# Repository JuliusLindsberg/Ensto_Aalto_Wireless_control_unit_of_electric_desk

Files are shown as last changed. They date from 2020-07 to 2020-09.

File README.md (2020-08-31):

# Wireless contol unit of electric desk
This is an Aalto University student project which aims to produce a functional prototype for a wireless controller of an electric desk. It is being developed
in collaboration with Ensto. Software will be published under a very permissive MIT license. See the licence file disclosed in this repository for details.
## Hardware
Our aim currently is to provide a working solution for only specific hardware. In our code there may or may not be useful generalizations for other types of
hardware choices too but quite certainly our solution is not going to work right out the box.
### Microcontroller: NRF52840
NRF52840 provides adequate support for bluetooth low energy and potential for control via NFC tags.
### Desk interface module
Module for interfacing between nrf52840 Dev Kit and Martela electric desk. Not necessarily compatible with other manufacturers. KiCad files included.
## Software

### Zephyr RTOS
Zephyr RTOS is an open source real time operating system which we use in this project. It provides some device bindings for the NRF52840.
There is also a fork of Zephyr maintained by Nordic Semiconductors which may have helpful examples. However, it unfortunately doesn't directly support NFR52840. 
https://github.com/nrfconnect/sdk-nrf
### C++
Programming language used is C++ or plain C. Not at all every feature of C++ is applicable due to constraints imposed by Zephyr OS.
See: https://docs.zephyrproject.org/1.9.0/kernel/other/cxx_support.html
### Our code
See doc/API.md for our API reference.
### Arduino table control folder
Contents of said folder don't have an active role in the project and are there just for storage purposes only. They were used to try out some concepts and
electrical circuits with a seperate arduino board simultaneously.
## Getting started
Developing and building our project should be not very different from building any other zephyr project. As a bit of a warning Zephyr's work enviroment
takes a lot of space (several gigabytes) from your hard drive.
Developing Zephyr programs should be possible with any major operating system but so far we have used only Linux so other enviroments are a case of untested waters.
### Setting up the work enviroment
In order to build our code follow these instructions:
https://docs.zephyrproject.org/latest/getting_started/index.html
Then clone this git repository inside the zephyrproject/zephyr folder. With a little tweaking it probably is possible to build the project ouside zephyr folder
too but just cloning this repository inside it seems to be the most convenient way available.
### Building our project
We use Zephyr's west tool to build our project in a similiar fashion as the tutorial above does. In order to build this project navigate to this
git repository in your shell and then execute:
```
west build -p auto -b nrf52840dk_nrf52840 ./
```

If your microcontroller is not NRF52840, then -b option should naturally be something else.
### Flashing into the microcontroller
```
west flash
```
should work just fine as with any other Zephyr project. flash command also tries to build the project if it isn't up to date. So the build command might be redundant for your workflow.

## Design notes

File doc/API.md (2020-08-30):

# Introduction

Software implementation of our project has been divided into c++ classes with the aim of encapsulating different functionalities in a logical way
and making everything more modular. API documentation will reflect this and therefore consist mostly of class descriptions.
Further explanations into the Zephyr's API reference can be found from: https://docs.zephyrproject.org/latest/boards/arm/nrf52840dk_nrf52840/doc/index.html
Despite it's name this document does not attempt to be a sterile API reference nor is it written by an expert on the topic. Instead, it is designed to explain
itself as well as possible from a subjective point of view in an attempt to help beginners to Zephyr avoid potential pitfalls.

Also it is imperative that a developer learns about Zephyr's inner workings from Zephyr's own tutorials. For example:
https://docs.zephyrproject.org/latest/guides/dts/intro.html#devicetree-intro <- which is a link to Zephyr project's device tree introduction in case the link dies.
Coming from personal experience, relying too heavily in deducting Zephyr's functionality from it's own code samples is not the most efficient method of
understanding it.

## DebugBlinker
DebugBlinker is a lightweight class that other classes can use for debugging. The final prototype will most likely have no use for LEDs as they will not be visible to
the end user. User of this class can create as many DebugBlinker objects as they want: they do not imply any sort of exclusive ownership of a led. However,
DebugBlinker's functionality currently is not thread-safe. LED4 is reserved for declaring an exeption: If LED4 is lit then some part of the program has called
declareException() function.

Non-Member functions:

### void declareException()

Lights up LED4 as a signal of exceptional circumstances faced somewhere during the execution of the program. It is supposed to replace a hole left by c++ standard library's exception handling as unfortunately Zephyr currently does not support it.

Member functions:

### DebugBlinker(int led_)

constructor for the DebugBlinker object. Supports leds 1, 2 and 3.
This is the only way to create an object of this class currently that is supported by the API.

### void ledOn()

Will light up a led. Supports leds 1, 2 and 3.

### void ledOff(int led)

Will power off a led. Supports leds 1, 2 and 3.

## DebugPrinter

DebugPrinter is another lightweight class that can be used for debugging. It was used in conjunction with Segger's J-Link SWOWiever tool for debug output.
Zephyr does also provide a function called printk for serial output but as it didn't work immediately for unknown reasons and although SWOViewer was a clumsy-ish
compromise it did eventually satisfy all of the group's needs for debugging and as such not much research was put into the problem which probably
would have been proven out to be very solvable. For further development using printk is still most likely a more preferable solution as it is being used in examples.

DebugPrinter has << operator overloading and it can be used as if it were std::cout with the exception that it is not a static class and should be instead
interacted through DebugPrinter objects. The first instance of DebugPrinter initializes SWO and SWOViewer and can be configured to work only after that.
Therefore it is recommended to create one DeubgPrinter Object right in the beginning of main(): another example of why printk would have indeed been more preferable.

Member functions:

### PrintString(char* string)
Prints a null-terminated-string to the SWO terminal. Can also be used with << operator
### PrintChar(char c)
Prints a single char to the SWO terminal. Can also be used with << operator
### PrintInt(int number)
Prints a number to the SWO terminal. Can also be used with << operator

## MotorController

This class is responsible for emulating the control signal of the desk's physical button presses. It determines which control signals should be listened to at what
times as a finite state machine. Currently it has two states: BUTTON and BLUETOOTH. However, additional states could be defined for additional states. BLUETOOTH state
might actually be a bit misrepresenting as it isn't actually directly responsible for listening to bluetooth signals. It just steers the table towards a target height
automatically based on steerRequest() function calls.

Currently, unfortunately, creating multiple objects of this class causes undefined behaviour!

### enum ButtonState
The electric desk's control button has four logical states it can be in. Our microcontroller tries to emulate them so that when a user presses the button
our controller functions as if it wouldn't be there at all catching the signal.

### enum ControlState
The MotorController internally functions as a finite state machine. Currently it has two states: BLUETOOTH and BUTTON. Every state has it's respective member
function responsible for sending the appropriate control signals to the motor and transitioning between states.

Member functions:

### void steerRequest(int newTargetHeight)

Tells MotorController to steer itself autonomously to a set target height. newTargetHeight represents reverse-engineered encoder steps which we spy and as such 
the distance traversed isn't strictly bound to any physical unit of height. Theoretically one encoder step does represent a certain constant distance but where
the table actually sets in within these boundaries could vary. The resolution of the table's encoder steps between the most upwards position and down position
is between 0 and somewhere around 400. Requests that differ from this range are currently not being ignored or cropped to physical limits by the function.

### ControlState getState()

Returns in which control state MotorController is in right now.

### void run()

a forever blocking function which keeps running the internal state machine logic to steer the table according to their respective user inputs.

### EncoderAnalyzer

This class analyzes the data which the desk's encoder provides with the help of an ADC pin. It is used by MotorController class internally and provides no useful
functionality outside of that.

## BluetoothModule.hpp

This is a more of a c-style interface responsible for implementing bluetooth functionality. It mostly has asynchronous functions and callback functions that describe
what is supposed to happen after event x happening. The c-style approach is because from our experience asynchronous functions combined with c++-style objects
do not really fit together well. It defines a custom bluetooth GATT service that has a 128-bit UUID of 6495c7ad-e0cc-4c2c-87c8-e8ad2f964b03 and advertises said service this UUID should be able to be changed with just one line of code. Naturally though the code of your BLE clients should be updated as well.

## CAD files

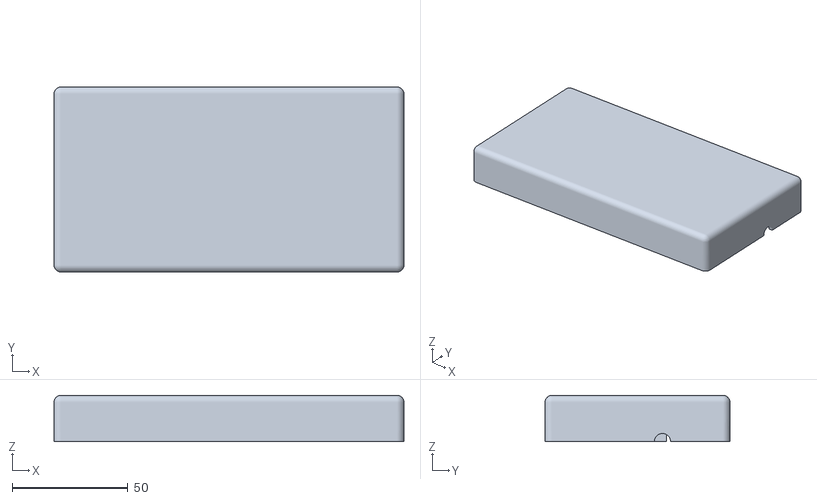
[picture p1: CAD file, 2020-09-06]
control_box_upper.stl
151.4 x 80.0 x 20.0

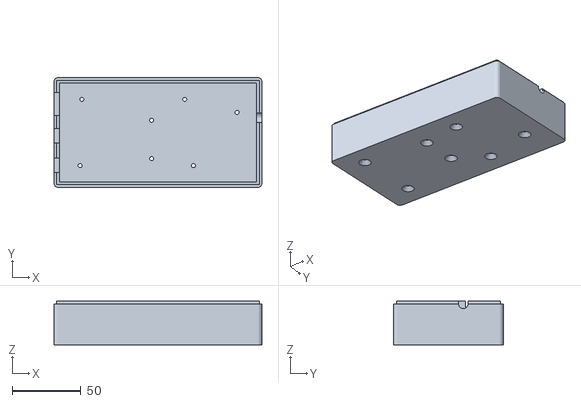
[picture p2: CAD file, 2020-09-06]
control_box_lower.stl
151.4 x 80.0 x 32.0

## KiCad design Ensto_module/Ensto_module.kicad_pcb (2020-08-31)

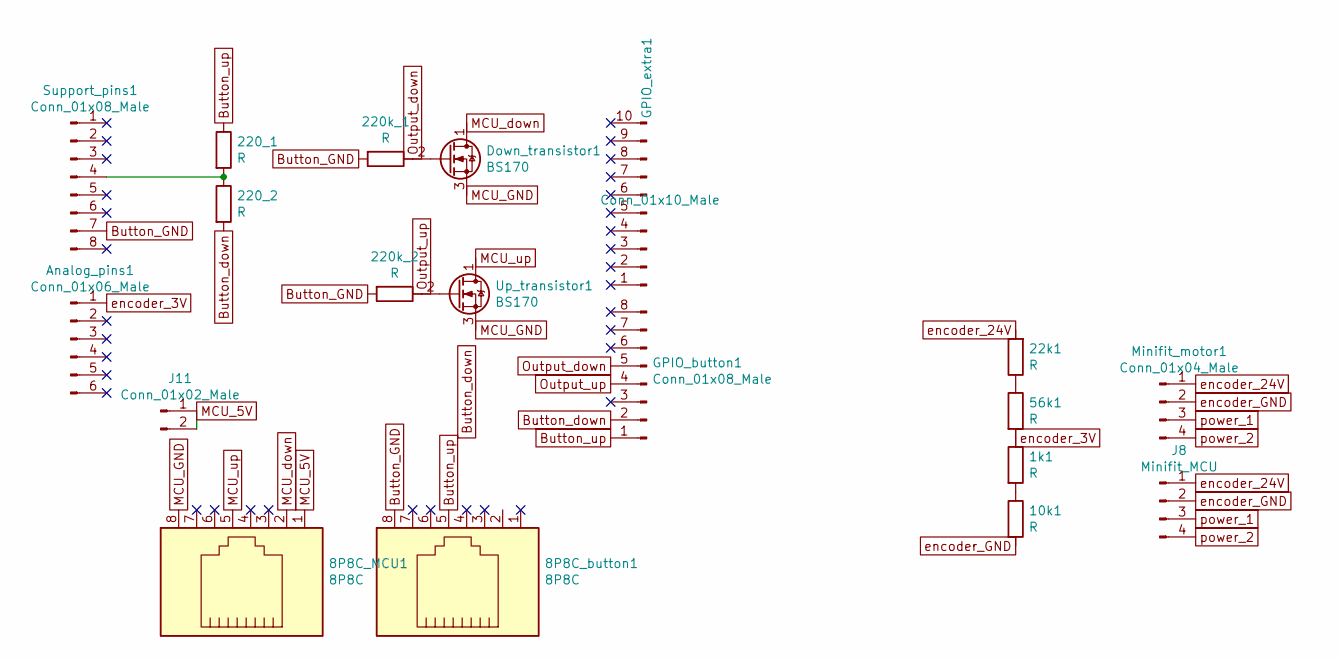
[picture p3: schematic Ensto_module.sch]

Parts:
1k1, 10k1, 22k1, 56k1, 220_1, 220_2, 220k_1, 220k_2: R; R_Axial_DIN0309_L9.0mm_D3.2mm_P15.24mm_Horizontal
8P8C_MCU1, 8P8C_button1: 8P8C; RJ45_Amphenol_54602-x08_Horizontal
Analog_pins1: Conn_01x06_Male; PinHeader_1x06_P2.54mm_Vertical
Down_transistor1: BS170; TO-92_Inline
GPIO_button1: Conn_01x08_Male; PinHeader_1x08_P2.54mm_Vertical
GPIO_extra1: Conn_01x10_Male; PinHeader_1x10_P2.54mm_Vertical
J8: Minifit_MCU; Molex_Mini-Fit_Jr_5569-04A2_2x02_P4.20mm_Horizontal
J11: Conn_01x02_Male; PinHeader_1x02_P2.54mm_Vertical
Minifit_motor1: Conn_01x04_Male; Molex_Mini-Fit_Jr_5569-04A2_2x02_P4.20mm_Horizontal
Support_pins1: Conn_01x08_Male; PinHeader_1x08_P2.54mm_Vertical
Up_transistor1: BS170; TO-92_Inline

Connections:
Button_GND: 8P8C_button1.8, 220k_1.2, 220k_2.2, Support_pins1.7
Button_down: 8P8C_button1.2, 220_2.2, GPIO_button1.2
Button_up: 8P8C_button1.5, 220_1.1, GPIO_button1.1
MCU_5V: 8P8C_MCU1.1, J11.1, J11.2
MCU_GND: 8P8C_MCU1.8, Down_transistor1.3 (S), Up_transistor1.3 (S)
MCU_down: 8P8C_MCU1.2, Down_transistor1.1 (D)
MCU_up: 8P8C_MCU1.5, Up_transistor1.1 (D)
unnamed: 1k1.2, 10k1.1
unnamed: 22k1.1, 56k1.1
unnamed: 220_1.2, 220_2.1, Support_pins1.4
Output_down: 220k_1.1, Down_transistor1.2 (G), GPIO_button1.5
Output_up: 220k_2.1, GPIO_button1.4, Up_transistor1.2 (G)
encoder_3V: 1k1.1, 56k1.2, Analog_pins1.1
encoder_24V: 22k1.2, J8.1, Minifit_motor1.1
encoder_GND: 10k1.2, J8.2, Minifit_motor1.2
power_1: J8.3, Minifit_motor1.3
power_2: J8.4, Minifit_motor1.4

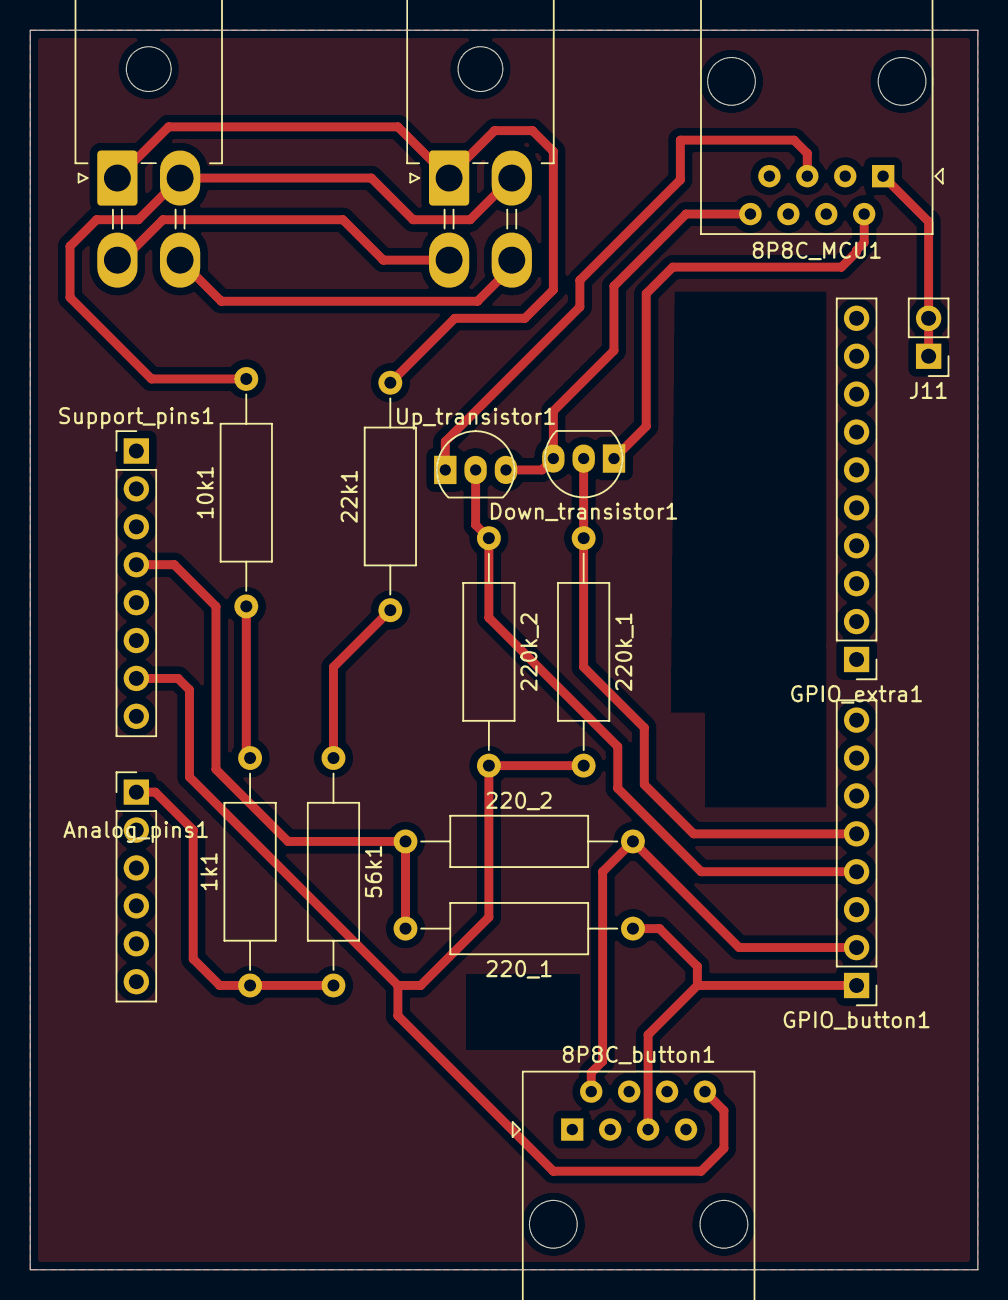
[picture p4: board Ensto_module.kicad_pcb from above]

Board: 2 copper layers, 63.5 x 83.1 mm, 19 parts (0 on the bottom side), 17 nets.

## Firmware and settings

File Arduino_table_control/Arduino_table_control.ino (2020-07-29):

/*
  Analog input, analog output, serial output

  Reads an analog input pin, maps the result to a range from 0 to 255 and uses
  the result to set the pulse width modulation (PWM) of an output pin.
  Also prints the results to the Serial Monitor.

  The circuit:
  - potentiometer connected to analog pin 0.
    Center pin of the potentiometer goes to the analog pin.
    side pins of the potentiometer go to +5V and ground
  - LED connected from digital pin 9 to ground

  created 29 Dec. 2008
  modified 9 Apr 2012
  by Tom Igoe

  This example code is in the public domain.

  http://www.arduino.cc/en/Tutorial/AnalogInOutSerial
*/

// These constants won't change. They're used to give names to the pins used:
const int signalUp = 2; // Gate1
const int signalDown = 8; // Gate2
const int BdownRead = 6; //button read1
const int BupRead = 4; //button read2
const int encoderPin = A0;

//bool up = 1;
//bool down = 1;
//bool BTup = 1;
//bool BTdown = 1;

// This variable is something from 0 to 1023 based on the voltage in encoderPin.
short encoderData = 0;

// This variable is 0, 1 or 2 based on analyzeSignalLevel() return
// and is explained there.
int signalLevel = 0;

// Temporary variables
// targetHeight is given by the user by bluetooth.
// tableHeight will be stored in flash memory.
// xyz is a variable that helps to execute BTdrive only once.
short targetHeight = 100;
short tableHeight = 0;
int xyz = 1;

// Encoder steps are counted based on encoder signal crossing these
//thresholds in analyzeSignalLevel.
#define THRESHOLD_LOW 910
#define THRESHOLD_HIGH 995



// levelAnalyser checks where the sample is in the expected signal.
// 0 is the valley, 1 is middle and 2 the peak.
// we only need positions 0 and 1 but position 2 is still here if we want
// to know the direction from the signal at some later time.
int analyzeSignalLevel(short sample){
  if (sample >= THRESHOLD_LOW){
    if (sample >= THRESHOLD_HIGH){
      return 2;
    }
    else {
      return 1;
    }
  }
  else {
    return 0;
  }
}

// analyzeTableHeight changes the variable for table height and will
// have to store it in flash memory in the future.
int analyzeTableHeight(short sample, bool up, bool down) {
  if (up && !down){
    if ((signalLevel != 2) && (analyzeSignalLevel(sample) == 2)) {
      tableHeight--;
    }
  }
  else if (down && !up){
    if ((signalLevel == 2) && (analyzeSignalLevel(sample) != 2)) {
      tableHeight++;
    }
  }
  signalLevel = analyzeSignalLevel(sample);
}

void setup() {
  // initialize serial communications at 9600 bps:
  Serial.begin(115200);

  pinMode(BdownRead, INPUT);
  pinMode(BupRead, INPUT);

  digitalWrite(signalUp, LOW);
  digitalWrite(signalDown, LOW);
  
}

// This function is to be executed only when bluetooth signal is received
// and does same things as main loop except with bluetooth variables (BTup, BTdown).
// BTdrive breaks, when button is pressed or desired height is reached.
void BTdrive(short targetHeight) {
  bool BTup = 1;
  bool BTdown = 1;
  bool Bup = 1;
  bool Bdown = 1;
  
  if (targetHeight > tableHeight) {
    BTup = 0;
  }
  else if (targetHeight < tableHeight) {
    BTdown = 0;
  }
  else {
    return;
  }
  
  while(!(targetHeight == tableHeight) && Bup && Bdown){
    encoderData = analogRead(A0);
    analyzeTableHeight(encoderData, BTup, BTdown);
    
    Bup = digitalRead(BupRead);
    Bdown = digitalRead(BdownRead);

    digitalWrite(signalUp, !BTup);
    digitalWrite(signalDown, !BTdown);

    Serial.print(THRESHOLD_LOW);
    Serial.print(",");
    Serial.print(THRESHOLD_HIGH);
    Serial.print(",");
    Serial.print("encoderDtata:");
    Serial.print(encoderData);
    Serial.print(",");
    Serial.print("targetHeight:");
    Serial.print(targetHeight);
    Serial.print(",");
    Serial.print("tableHeight:");
    Serial.println(tableHeight);
  }
}


void loop() {

  bool up = 1;
  bool down = 1;
  
  up = digitalRead(BupRead);
  down = digitalRead(BdownRead);
  
  digitalWrite(signalUp, !up);
  digitalWrite(signalDown, !down);

  encoderData = analogRead(A0);

// BAD CODE
  if(xyz){
    BTdrive(targetHeight);
  }
  xyz = 0;
// DO BETTER

  analyzeTableHeight(encoderData, up, down);
  
  Serial.print(THRESHOLD_LOW);
  Serial.print(",");
  Serial.print(THRESHOLD_HIGH);
  Serial.print(",");
  Serial.print("encoderDtata:");
  Serial.print(encoderData);
  Serial.print(",");
  Serial.print("targetHeight:");
  Serial.print(targetHeight);
  Serial.print(",");
  Serial.print("tableHeight:");
  Serial.println(tableHeight);
  //Serial.print(up);
  //Serial.println(",");
  //Serial.print(down);
  //Serial.println(",");

  delay(3);
}

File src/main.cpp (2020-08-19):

#include <zephyr.h>
#include "DebugBlinker.hpp"
#include "MotorController.hpp"

#include "DebugPrinter.hpp"
#include "BluetoothModule.hpp"
#include <string.h>
#define ONE_SECOND 1000
#include <stdio.h>
//for usb debug console messages
#include <sys/printk.h>
#include <sys/util.h>

void main(void)
{
	DebugBlinker ledOne(1);
	DebugBlinker ledTwo(2);
	DebugBlinker ledThree(3);
	DebugPrinter printer;
	ledThree.ledOff();
	ledOne.ledOff();
	ledTwo.ledOff();
	MotorController controller;
	startBluetooth(&controller);
	controller.run();
}

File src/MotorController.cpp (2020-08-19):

#include "MotorController.hpp"

#include "DebugBlinker.hpp"
#include <zephyr.h>
#include <devicetree.h>
#include <drivers/gpio.h>
#include <dt-bindings/gpio/gpio.h>
#include "DebugPrinter.hpp"
//Button up input pin 1 of device GPIO_1 is (ARDUINO D0, p1.01) in nrf52840dk
#define BUTTON_UP_INPUT 1
//p1.02
#define BUTTON_DOWN_INPUT 2
//p1.04
#define BUTTON_UP_OUTPUT 4
//p1.05
#define BUTTON_DOWN_OUTPUT 5


struct device* pinDevice;
bool MCInitialized = false;

MotorController::MotorController()
{
    setState(ControlState::BUTTON);
    targetHeight = -1;
    if(!MCInitialized)
    {
        MCInitialized = true;
        pinDevice = device_get_binding("GPIO_1");
        
        if(pinDevice == NULL)
        {
            declareException();
        }
        //init digital input pins
        gpio_pin_configure(pinDevice, BUTTON_UP_INPUT, GPIO_INPUT);
        gpio_pin_configure(pinDevice, BUTTON_DOWN_INPUT, GPIO_INPUT);
        //init digital output pins
        gpio_pin_configure(pinDevice, BUTTON_DOWN_OUTPUT, GPIO_OUTPUT_LOW);
        gpio_pin_configure(pinDevice, BUTTON_UP_OUTPUT, GPIO_OUTPUT_LOW);
    }
}

ButtonState MotorController::readButtonState()
{
    int retUP = gpio_pin_get_raw(pinDevice, BUTTON_UP_INPUT);
    int retDOWN = gpio_pin_get_raw(pinDevice, BUTTON_DOWN_INPUT);

    if( retUP == 1 && retDOWN == 0)
    {
        return ButtonState::DOWN;
    }
    else if(retUP == 0 && retDOWN == 1)
    {
        return ButtonState::UP;
    }
    else if(retUP == 0 && retDOWN == 0)
    {
        return ButtonState::BOTH;
    }
    else if(retUP == 1 && retDOWN == 1)
    {
        return ButtonState::NOT_PRESSED;
    }
    else
    {
        //in case of an unknown state the safest signal to send is ButtonState::NOT_PRESSED as then it won't move the desk due to potential error states
        declareException();
        return ButtonState::NOT_PRESSED;
    }
}

void MotorController::steerMotor(ButtonState directive)
{
    DebugPrinter printer;
    if(directive == ButtonState::UP)
    {
        gpio_pin_set_raw(pinDevice, BUTTON_UP_OUTPUT, 1);
        gpio_pin_set_raw(pinDevice, BUTTON_DOWN_OUTPUT, 0);
        printer << "UP\n";
    }
    else if(directive == ButtonState::DOWN)
    {
        gpio_pin_set_raw(pinDevice, BUTTON_UP_OUTPUT, 0);
        gpio_pin_set_raw(pinDevice, BUTTON_DOWN_OUTPUT, 1);
        printer << "DOWN\n";
    }
    else if(directive == ButtonState::BOTH)
    {
        gpio_pin_set_raw(pinDevice, BUTTON_UP_OUTPUT, 1);
        gpio_pin_set_raw(pinDevice, BUTTON_DOWN_OUTPUT, 1);
        printer << "BOTH\n";
    }
    else
    {
        printer << "NOTPRESSED\n";
        gpio_pin_set_raw(pinDevice, BUTTON_UP_OUTPUT, 0);
        gpio_pin_set_raw(pinDevice, BUTTON_DOWN_OUTPUT, 0);
    }
}

bool MotorController::steerTowardsTarget(int tableHeight)
{
    if(targetHeight < 0)
    {
        return true;
    }
    if(analyzer.getTargetDirection() == TargetDirection::DOWN_DIRECTION)
    {
        //goal reached
        if(tableHeight <= targetHeight)
        {
            return true;
        }
        //keep steering
        else
        {
            steerMotor(ButtonState::DOWN);
        }
    }
    else if(analyzer.getTargetDirection() == TargetDirection::UP_DIRECTION)
    {
        //goal reached
        if(tableHeight >= targetHeight)
        {
            return true;
        }
        //keep steering
        else
        {
            steerMotor(ButtonState::UP);
        }
    }
    else
    {
        //this shouldnt happen. If we get here there's a bug in code.
        declareException();
        return true;
    }
    //goal has not been reached
    return false;
}

ControlState MotorController::controlStateButton(int tableHeight, ButtonState buttonState)
{
    if(buttonState == ButtonState::NOT_PRESSED)
    {
        steerMotor(ButtonState::NOT_PRESSED);
        analyzer.setTargetDirection(TargetDirection::NONE);
    }
    else if(buttonState == ButtonState::DOWN)
    {
        analyzer.setTargetDirection(TargetDirection::DOWN_DIRECTION);
        //user wants to steer downwards via button press
        steerMotor(ButtonState::DOWN);
    }
    else if(buttonState == ButtonState::UP)
    {
        //user wants to steer upwards via button press
        analyzer.setTargetDirection(TargetDirection::UP_DIRECTION);
        steerMotor(ButtonState::UP);
    }
    else if(buttonState == ButtonState::BOTH)
    {
        //no idea what is supposed to happen
        steerMotor(ButtonState::BOTH);
    }
    return ControlState::BUTTON;
}
ControlState MotorController::controlStateBluetooth(int tableHeight, ButtonState buttonState)
{
    if(buttonState != ButtonState::NOT_PRESSED)
    {
        return ControlState::BUTTON;
    }
    //target achieved
    if(steerTowardsTarget(tableHeight))
    {
        analyzer.setTargetDirection(TargetDirection::NONE);
        targetHeight = -1;
        return ControlState::BUTTON;
    }
    return ControlState::BLUETOOTH;
}

void MotorController::run()
{
    DebugPrinter printer;
    while(1)
    {
        k_msleep(1);
        //these steps are the same for every state
        int tableHeight = analyzer.updateAndGetDeskPosition();
        ButtonState buttonState = readButtonState();
        //finite state machine spesific states
        printer << "STATE: " << getState() << "\n" << " tableHeight: " << tableHeight << "\n";
        switch (getState())
        {
        case ControlState::BUTTON:
            setState(controlStateButton(tableHeight, buttonState));
            break;
        case ControlState::BLUETOOTH:
            setState(controlStateBluetooth(tableHeight, buttonState));
            break;
        default:
            //currently this should be logically impossible. There is no designated error state
            declareException();
            break;
        }
    }
};

ControlState MotorController::getState()
{
    return controlState;
}

void MotorController::setState(ControlState newState)
{
    controlState = newState;
}

void MotorController::steerRequest(int newTargetHeight)
{
    setState(ControlState::BLUETOOTH);
    targetHeight = newTargetHeight;
    if( analyzer.lastDeskPosition() < newTargetHeight )
    {
        analyzer.setTargetDirection(TargetDirection::UP_DIRECTION);
    }
    else if( analyzer.lastDeskPosition() > newTargetHeight )
    {
        analyzer.setTargetDirection(TargetDirection::DOWN_DIRECTION);
    }
    else
    {
        analyzer.setTargetDirection(TargetDirection::NONE);
        targetHeight = -1;
        declareException();
    }
}

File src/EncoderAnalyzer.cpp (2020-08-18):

#include "EncoderAnalyzer.hpp"
#include "DebugPrinter.hpp"
#include "DebugBlinker.hpp"

#include <devicetree.h>
#include <drivers/adc.h>
#include <drivers/gpio.h>
#include <stdio.h>
#include <stdlib.h>
#include <string.h>
#include "hal/nrf_saadc.h"

#define ADC_NODE_LABEL DT_LABEL(DT_NODELABEL(adc))
#define SAMPLE_BUFFER_SIZE 2
#define SAMPLE_RESOLUTION 10
//SAMPLE_GAP_MILLISECONDS 0 basically means "do it ASAP"
#define SAMPLE_GAP_MILLISECONDS 0
#define INPUT_CHANNEL 1
#define OVERSAMPLING 3
#define CALIBRATE 1
#define EXTRA_SAMPLINGS 0

// Signal thresholds to compare the signal to (if its peak middle or valley)
// subject to change depending on the microcontroller used to test
#define THRESHOLD_LOW 700
#define THRESHOLD_HIGH 795

bool EA_initialized = false;
device* adcDevice;
short sampleBuffer[SAMPLE_BUFFER_SIZE] = {0};

static struct adc_channel_cfg adcChannelConfig = {
    .gain = ADC_GAIN_1_6,
    .reference = ADC_REF_INTERNAL,
    .acquisition_time = ADC_ACQ_TIME_DEFAULT,
    //WARNING: these will be defined during runtime and changing them here doesn't change anything
    .channel_id = 0,
    .differential = 0,
#if defined(CONFIG_ADC_CONFIGURABLE_INPUTS)
    .input_positive = NRF_SAADC_INPUT_AIN1,     //input negative only for differential signal
#endif
};

const struct adc_sequence_options SampleOptions = {
    .interval_us = 0,
    .callback = NULL,
    .extra_samplings = EXTRA_SAMPLINGS
};
const struct adc_sequence sampleSequence = {
.options = &SampleOptions,
.channels = BIT(INPUT_CHANNEL),
.buffer = sampleBuffer,
.buffer_size = SAMPLE_BUFFER_SIZE,
.resolution = SAMPLE_RESOLUTION,
.oversampling = OVERSAMPLING,
.calibrate = CALIBRATE
};

//constructor automatically initializes ADC. The interface of this class is channel spesific
//and the channel to be used will be given when an object is constructed. Valid channels are 0-7(?)

EncoderAnalyzer::EncoderAnalyzer()
{
    if(!EA_initialized)
    {
        //ad hoc
        targetDirection = TargetDirection::NONE;
        sample = 0;
        lastSample = 0;
        signalLevel = 0;
        //will be retrieved from memory
        encoderStep = 1;
        adcDevice = device_get_binding("ADC_0");
        //inputChannel = INPUT_CHANNEL;
        if(!adcDevice)
        {
            declareException();
            return;
        }
        adcChannelConfig.channel_id = INPUT_CHANNEL;
#if defined(CONFIG_ADC_CONFIGURABLE_INPUTS)
        adcChannelConfig.input_positive = INPUT_CHANNEL+1;
#endif
        int ret = adc_channel_setup(adcDevice, &adcChannelConfig);
        if(ret != NULL)
        {
            declareException();
        }
        EA_initialized = true;
    }
}



//fills sampleBuffer with samples
short EncoderAnalyzer::getSample()
{
    //extra samples without multiple calls to adc_read probably requires a callback function to be setup (?)
    adc_read(adcDevice, &sampleSequence);
    return sampleBuffer[0];
}

int EncoderAnalyzer::analyzeLevel(short sample){
  if (sample >= THRESHOLD_LOW){
    if (sample >= THRESHOLD_HIGH){
      return 2;
    }
    else {
      return 1;
    }
  }
  else {
    return 0;
  }
}

void EncoderAnalyzer::analyzeStep(short sample) {
  if (targetDirection == TargetDirection::UP_DIRECTION){
    if ((signalLevel != 2) && (analyzeLevel(sample) == 2)) {
      encoderStep++;
    }
  }
  else if (targetDirection == TargetDirection::DOWN_DIRECTION) {
    if ((signalLevel == 2) && (analyzeLevel(sample) != 2)) {
      encoderStep--;
    }
  }
  signalLevel = analyzeLevel(sample);
}

int EncoderAnalyzer::updateAndGetDeskPosition()
{
  short debugSample = getSample();
  DebugPrinter printer;
  printer << debugSample << " - sample voltage reading\n";
  analyzeStep(debugSample);
  return encoderStep;
}

int EncoderAnalyzer::lastDeskPosition()
{
  return encoderStep;
}

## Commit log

2020-07-10 This commit is way too big...
    [DebugBlinker.cpp, EncoderAnalyzer.cpp, MotorController.cpp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]
2020-07-10 debugging functionality of EncoderAnalyzer and GPIO pins
2020-07-13 testing Zephyr's ADC library
2020-07-13 got EncoderAnalzer working-ish
2020-07-14 refactored SWO printing into a designated class with c++-like operator support.
2020-07-14 added a new branch for developing encoder
2020-07-14 added support for reading samples
2020-07-14 Update EncoderAnalyzer.cpp
    Added encoder data analysis with 2 functions (analyzer and levelAnalyzer)
2020-07-14 Update EncoderAnalyzer.hpp
    Added encoder data analysis (analyze() and levelAnalyzer())
2020-07-14 minor tweaks to EncoderAnalyzer
2020-07-15 Did some cleanup on EncoderAnalyzer class and fixed behavior in other classes
    [EncoderAnalyzer.cpp, MotorController.cpp, main.cpp]
2020-07-15 fixed main.cpp from merge conflict
    [main.cpp]
2020-07-16 Added some debugging data to be printed for calibration
2020-07-16 made MotorController compatible with steering signals coming from from bt
2020-07-16 commented out non-compiling code for encoder and master branch
2020-07-17 Revert "un-ruined master branch."
    This reverts commit b874a9f5906d5917e943144e58ad4893c775bcc7.
    [main.cpp]
2020-07-17 Revert "commented out non-compiling code for encoder and master branch"
    This reverts commit 22ffca109a7894fbcfb8070cc9c8c28147676f8e.
2020-07-20 replicated a zephyr sample bluetooth functionality in c++ without helper macros
2020-07-27 Updated some of the documentation and removed useless virtual led concept
2020-07-29 trying to debug why beacon behavior doesn't work
    [main.cpp]
2020-07-30 created a basic type of finite state machine to MotorController
2020-07-31 implemented button control successfully (untested in exceptional conditions)
2020-08-07 switching a branch
2020-08-07 removed the debug 'bluetooth' steer instruction from beginning
2020-08-19 removed useless kernel sleep after reset
    [main.cpp]
2020-08-31 Add files via upload
    KiCad files for Bluetooth module.
    [Ensto_module.kicad_pcb, Ensto_module.sch]
2020-09-06 Add files via upload
    Added Control Box 3D-model upper and lower part files.
    [control_box_lower.stl, control_box_upper.stl]
